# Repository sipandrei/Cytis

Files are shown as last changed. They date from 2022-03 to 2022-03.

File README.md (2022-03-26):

# Cytis

## Un aparat telecomandat pentru modificarea presiunii la biciclete

## Rezumat

De câte ori ai mers la o tură cu bicicleta și ai uitat să îți verifici presiunea din roți înainte de a pleca? Sau Poate ai decis să o iei pe macadam când aveai în plan doar asfalt lin și te-ai cam zdruncinat. Dacă ai pățit acestea, ei bine, Cytis îți poate veni în ajutor, dându-ți posibiliatea de a-ți regla presiunea direct de la telefon, sau orice dispozitiv cu bluetooth, acesta așteptând comenzile tale pe butucul roții. Din când în când va trebui schimbată canistra de aer.

## Din ce este Cytis compus?

Pentru început, acest proiect are două jumătăți: interfața web și dispozitivul în sine. Interfața web este construită în Ruby on Rails și configurată ca un Progressive Web App, pentru a putea fi instalată. Pe site este posibilă creearea unui cont(pentru autentificare am folosit Devise). Comunicarea este realizată folosind tehnologia Web Bluetooth. Dispozitivul este bazat pe un Arduino Nano cuplat cu un modul HM-10 pentru bluetooth. aerul de intrare este preluat dintr-o canistră de CO2, iar întreaga instalație este montată pe butucul roții pentru a încurca mai puțin.

**Proiectul se află în stadiul de prototip, o variantă de producție fiind mult mai mică și mai fiabilă, însă am fost limitat de buget**

## Cele patru lucruri principale pe care le face

- Procesează comenzile de la interfața web
- Citește presiunea actuală
- Umflă cauciucul
- Dezumflă cauciucul

## Tehnologii utilizate

- Arduino - partea fizică
- Ruby on Rails - backend-ul interfeței web
- HTML, CSS, JS - frontend-ul interfeței web
- Web Bluetooth - comunicarea cu dispozitivul fizic - limitează browserul ce poate fi utilizat
- PWA - permite instalarea site-ului

## Cerințe de Sistem

- Dispozitiv cu bluetooth, care poate accesa Internetul folosind Chrome(sau derivat) sau Opera

## Dorești să rulezi interfața web local?

- Ai nevoie de Ruby on Rails `v6.1.4` și Ruby `v3.0.3` instalat
- Rulează `git clone git@github.com:sipandrei/Cytis_frontend.git`
- Rulează `bundle install`
- Rulează `rails db:migrate`
- Pornește serverul și ar trebui să ai o interfață web Cytis ce rulează local

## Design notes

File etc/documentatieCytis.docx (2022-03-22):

Cytis

Aparat de ajustat presiunea cauciucurilor de la biciclete

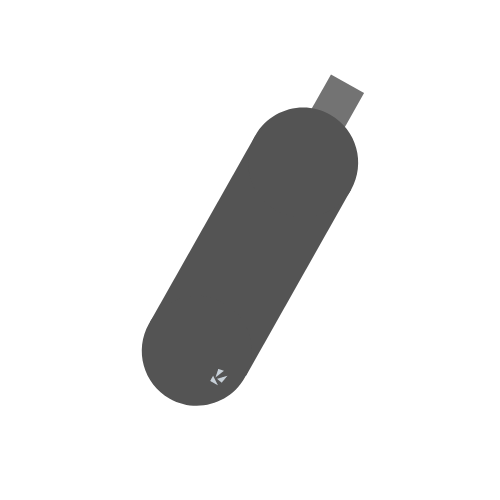
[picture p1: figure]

Elev: Pontoș Silviu Andrei

Profesor Coordonator: Burcuș Andrea

Martie 2022

Ce este Cytis?

Cytis este un proiect pe care l-am avut în minte o vreme bună, iar cu ocazia Olimpiadei de Inovare și Creație digitală – Infoeducație 2022, am fost motivat să îl pun în practică.

De unde a venit ideea. Care îi este scopul?

Fiind un adept al mersului cu bicicleta atât pe dealuri cât și pe șosele, în una dintre ieșirile mele combinate, am observat că fie aveam pe asfalt o presiune prea joasă, astfel fiind nevoit să depun mai mult efort pentru a mă deplasa cu o anumită viteză, fie aveam pe un drum noroios o presiune cu mult peste una cu care să mă simt în siguranță. O altă problemă apărea când nu eram obișnuit cu o anumită anvelopă sau pur și simplu uitam să verific presiunea înaintea turei, rezultatul evident fiind o pană în mijlocul sălbăticiei.

*POZA PANA IN SALBATICIE*

Așadar, pentru a evita situațiile neplăcute enumerate mai sus și după ce am auzit de un dispozitiv care măsoară presiunea în timpul deplasării, am decis că nu ar fi rău dacă aceasta ar putea fi și ajustată, lucru care nu l-am întâlnit încă la nici un produs.

Notă: În starea actuală proiectul reprezintă mai mult un Proof of Concept, o variantă de producție fiind mult mai compactă, dar, fiind limitat de bugetul pe care l-am avut, doar până aici am ajuns.

Bine, bine, dar numele de unde vine?

Denumirea de Cytis provine de la principala sursă de inspirație, și anume sistemele de umflare centralizată a cauciucurilor (central tire inflation system - CTIS), găsite cu precădere pe vehiculele militare cu roți pneumatice.

Cum funcționează?

Cytis este format din două elemente care lucrează împreună, și anume interfața web și partea fizică.

Interfața web

Interacțiunea cu dispozitivul se poate realiza folosind orice dispozitiv cu Bluetooth și care poate accesa Internetul prin intermediul Google Chrome sau Opera.

Interfața web a fost construită utilizând framework-ul Ruby on Rails pentru a permite utilizatorului să își salveze mai multe profile pentru presiune, astfel fiind mai rapidă setarea acesteia. Un profil conține două valori numerice, una pentru roata din spate, una pentru cea din față – în unitatea de măsură psi.

*POZĂ PRESET*

Controlarea propriu-zisă a presiunii se realizează pe o pagină dedicată a site-ului, iar conectarea se realizează cu ajutorul tehnologiei Web Bluetooth (de aici provenind limitarea la cele două browsere, fiind singurele care, la momentul scrierii, au implementată această tehnologie), care permite trimiterea și primirea de date de la dispozitive BLE (bluetooth low energy). Pe această pagină se poate conecta la Cytis, seta presiunea dorită și citi presiunea actuală.

*POZĂ INFLATOR*

Un adaos la interfața web este faptul că aceasta poate fi instalată, fiind configurată ca un PWA (progressive web app), dar la momentul actual service workerul nu salvează local paginile.

Partea Fizică

*POZĂ ASAMBLATE*

Centrul componentei hardware îl reprezintă un Arduino Nano, utilizat datorită dimensiunii reduse pe care o are și faptului că aveam acces la o astfel de placă. Comunicarea prin Bluetooth e realizată prin intermediul unui modul BLE HM-10, la care am adăugat pe pinul RX un reducător de la 5V la 3.3V format din două rezistoare(unul de 2kohm și celălalt de 4.7kohm).

*POZĂ CIRCUIT*

Atât pentru partea de „servire”, acum partea de muncă. Sursa principală de energie este o baterie de 9V. Ajustarea efectivă a presiunii este realizată utilizând două valve solenoid 2V025-06, una de ieșire una de intrare, conectate la Arduino folosind o punte h l298n. Citirea presiunii este realizată cu ajutorul unui transducer generic cu filet 1/4in. Presiunea pentru intrare vine dintr-o canistră de C02.

Toate elementele relevante pentru lucrul cu aerul sunt interconectate folosind tuburi pneumatice industriale de 6mm și două cupalje în T. Conectarea cu anvelopa se face prin intermediul valvei de pe jantă, prin intermediul unui adaptor care deschide valva de tip Schrader.

*POZĂ CAD LAYOUT*

Carcasa a fost proiectată folosind programul Onshape și ulterior printată 3D folosind PLA, aceasta fiind menită să fie prinsă pe butucul roții pentru a minimiza efectul greutății aparatului în caracteristicile de controlare a bicicletei.

Credite

Pentru codul necesar utilizării Web Bluetooth am avut ca bază următorul articol:

https://loginov-rocks.medium.com/how-to-make-a-web-app-for-your-own-bluetooth-low-energy-device-arduino-2af8d16fdbe8

Mulțumesc magazinului de biciclete CsaBike pentru componentele specifice pentru bicicletă, magazinului Domus Energy pentru cablurile pe care le-am primit și prietenilor care m-au ajutat cu imprimarea carcasei.

Surse

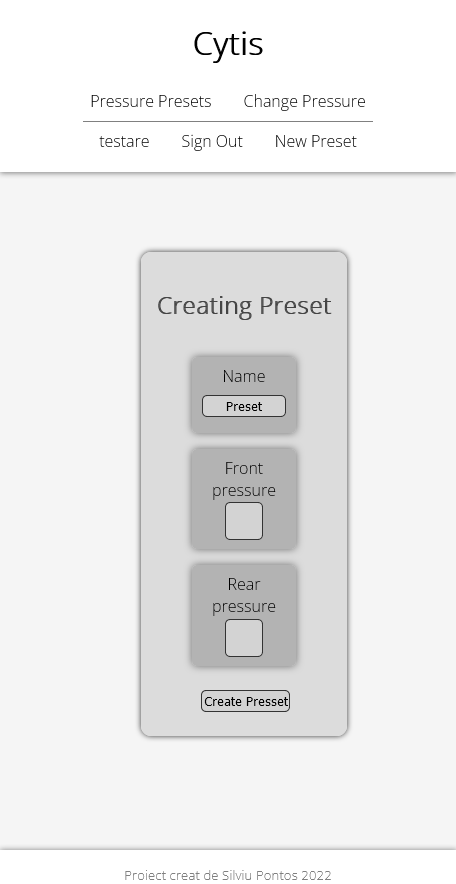
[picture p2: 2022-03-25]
etc/Captura de ecran 2022-03-25 la 08.28.39.png

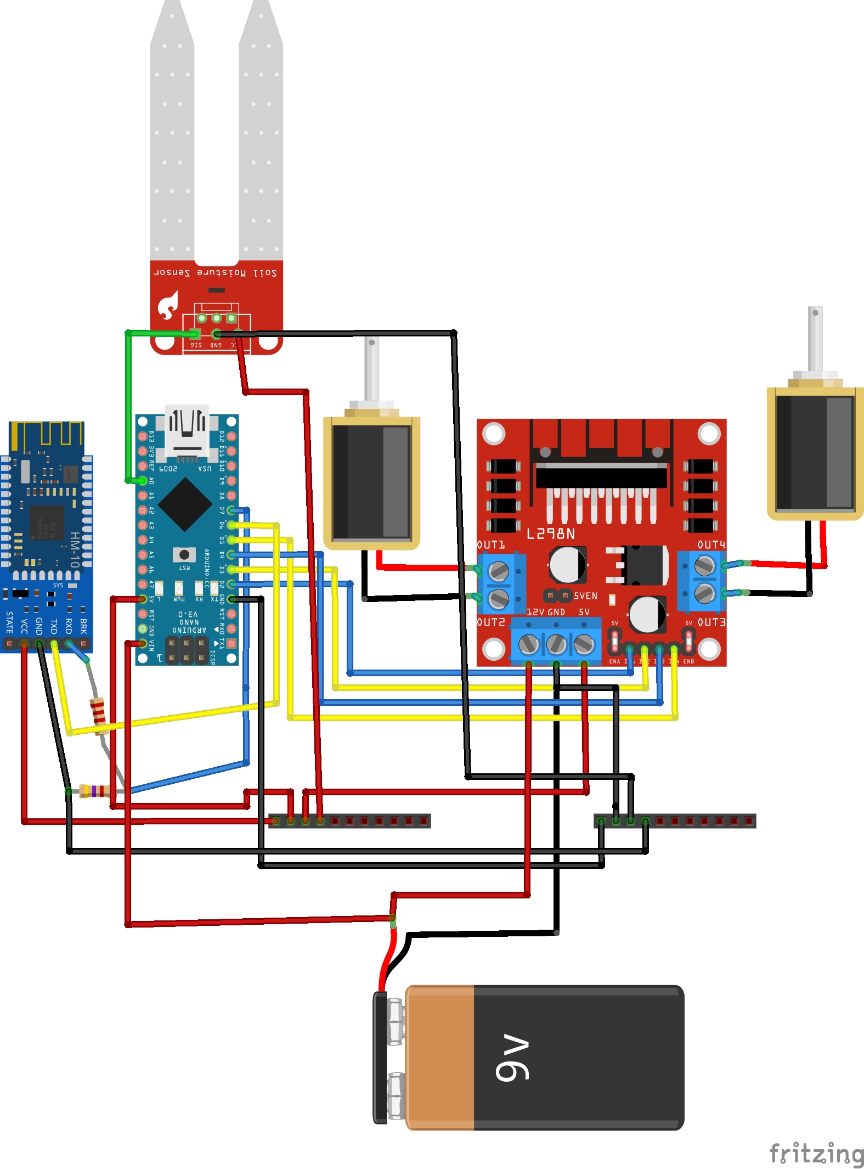
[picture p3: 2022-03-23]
etc/Cytis_bb.jpg

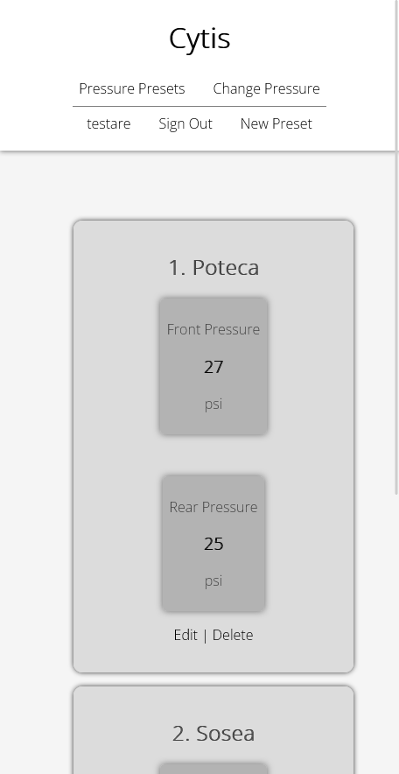
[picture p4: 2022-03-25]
etc/Captura de ecran 2022-03-25 la 07.57.08.png

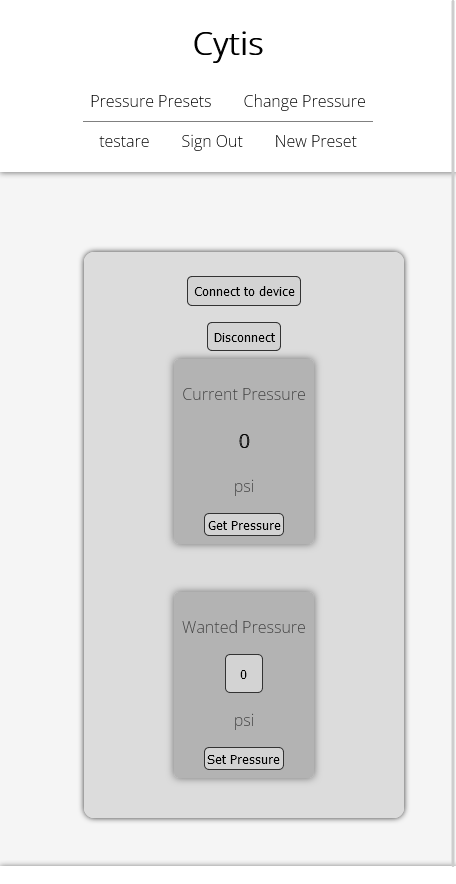
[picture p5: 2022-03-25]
etc/Captura de ecran 2022-03-25 la 07.58.17.png

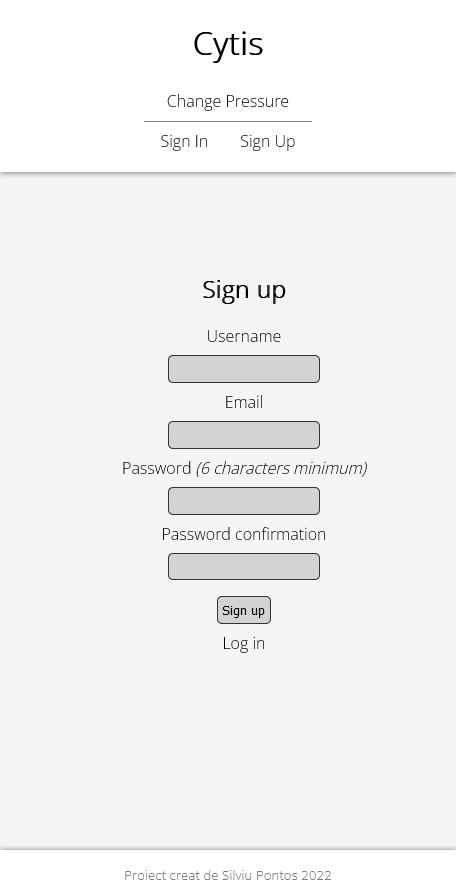
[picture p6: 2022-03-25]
etc/Captura de ecran 2022-03-25 la 08.36.11.png

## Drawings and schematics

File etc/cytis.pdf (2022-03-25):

Documentație

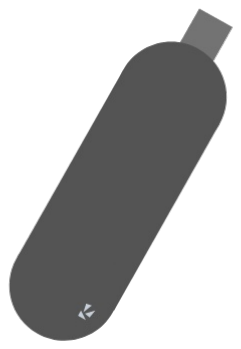
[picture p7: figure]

Elev: Pontoș Silviu Andrei

Profesori Coordonatori:
Burcuș Andrea, Hotea
Cornelia

# Cytis

Aparat de ajustat presiunea cauciucurilor de la biciclete

## Ce este Cytis?

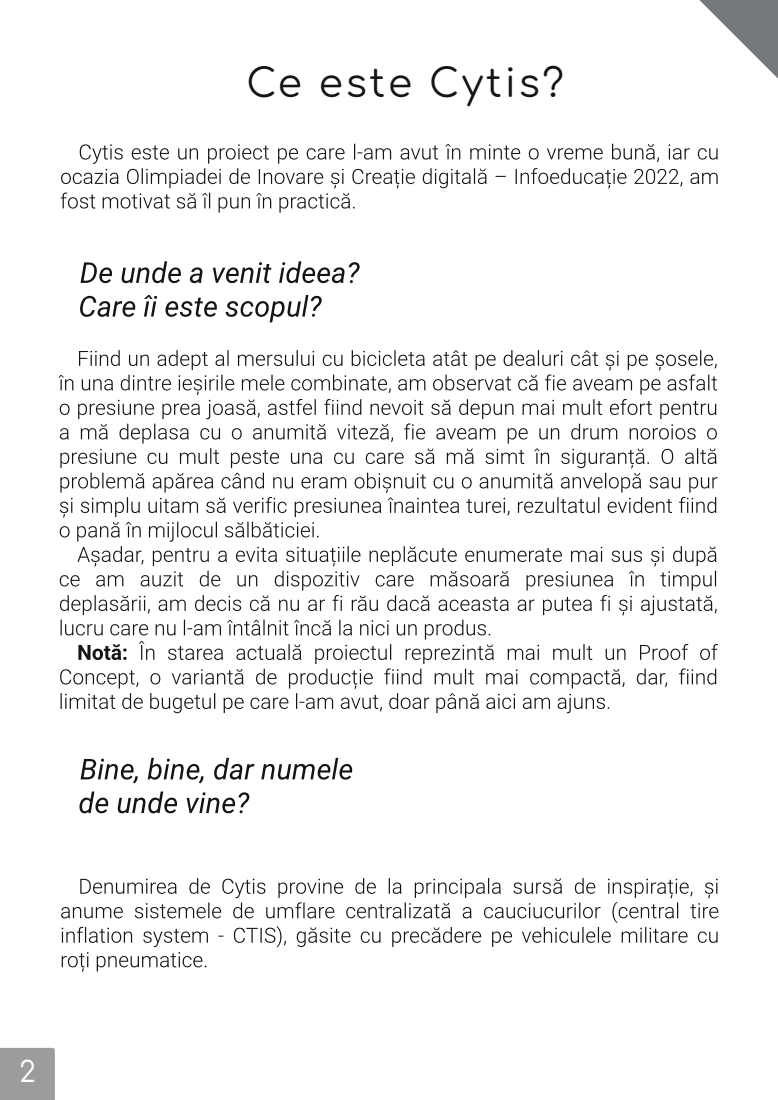
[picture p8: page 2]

## Cum funcționează?

## Interfața web

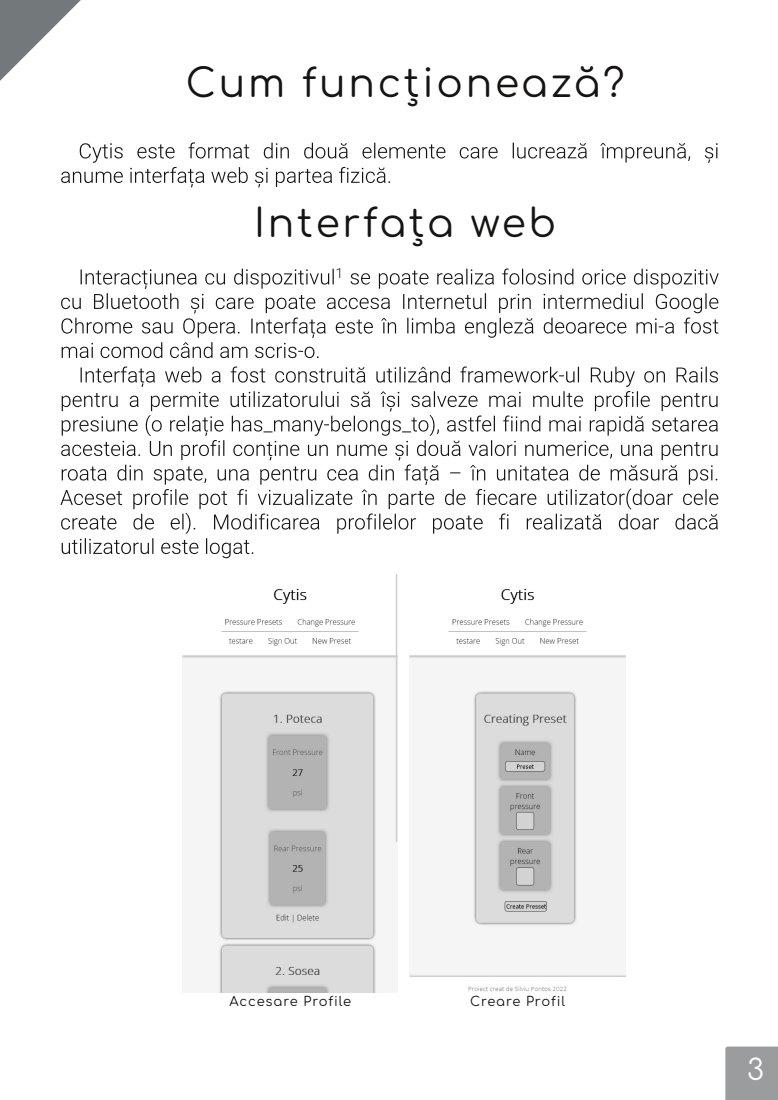
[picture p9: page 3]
Accesare Profile; Creare Profil

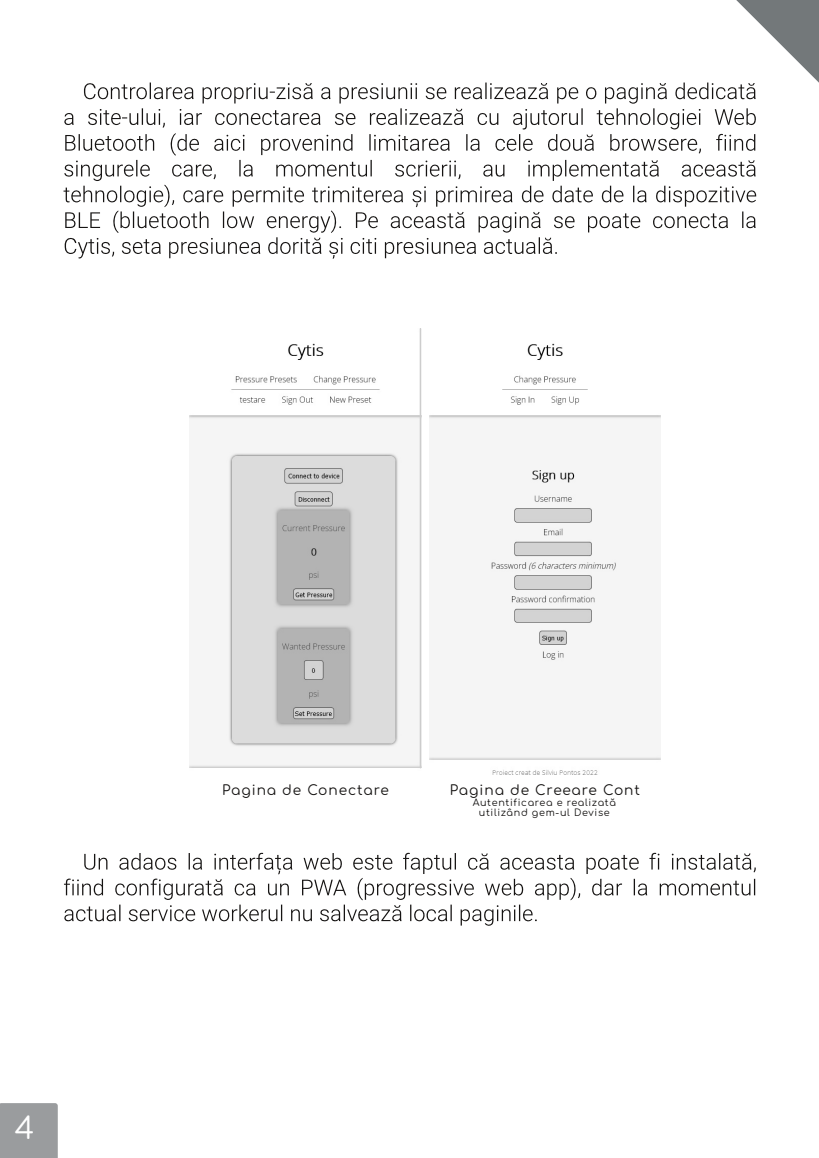
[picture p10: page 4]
Pagina de Conectare; Pagina de Creeare Cont

Autentificarea e realizată
utilizând gem-ul Devise

## Partea Fizică

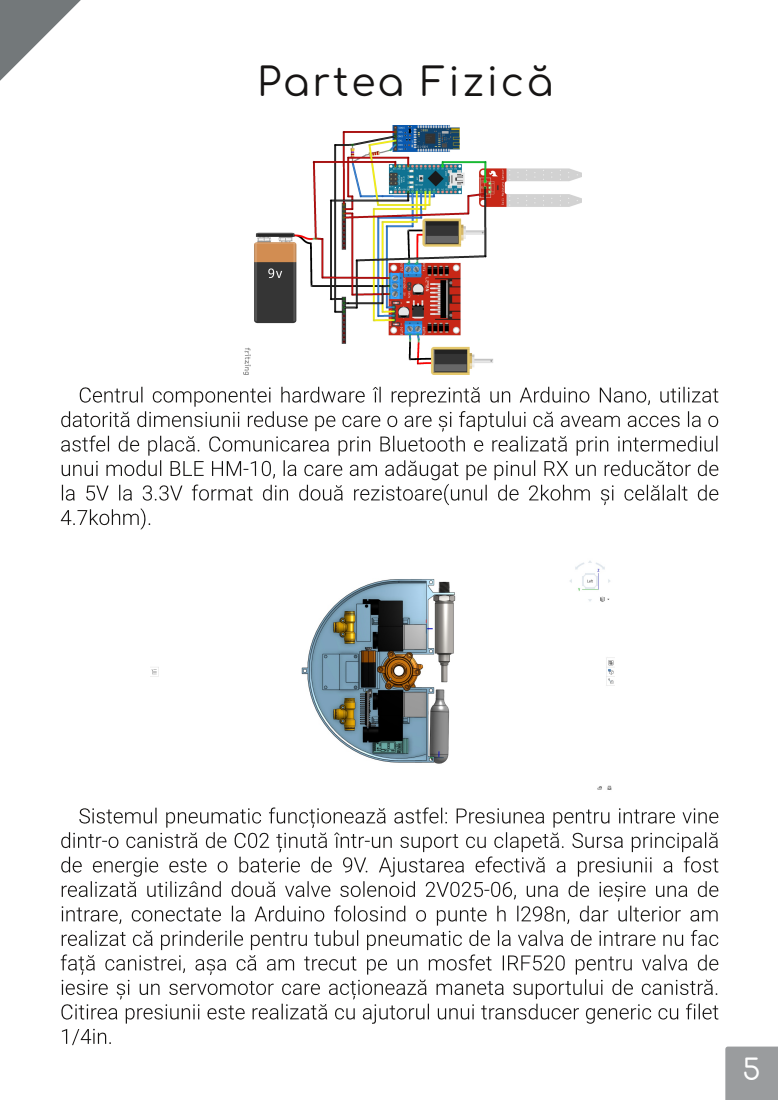
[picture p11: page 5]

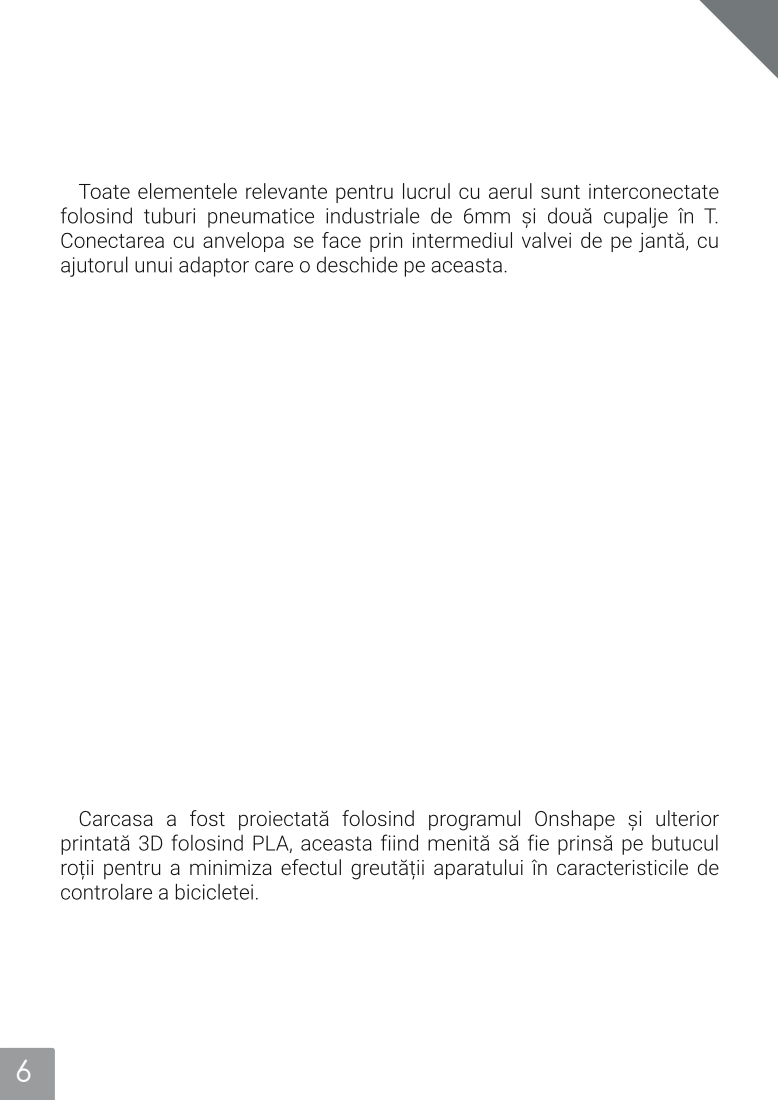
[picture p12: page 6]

## Mențiuni

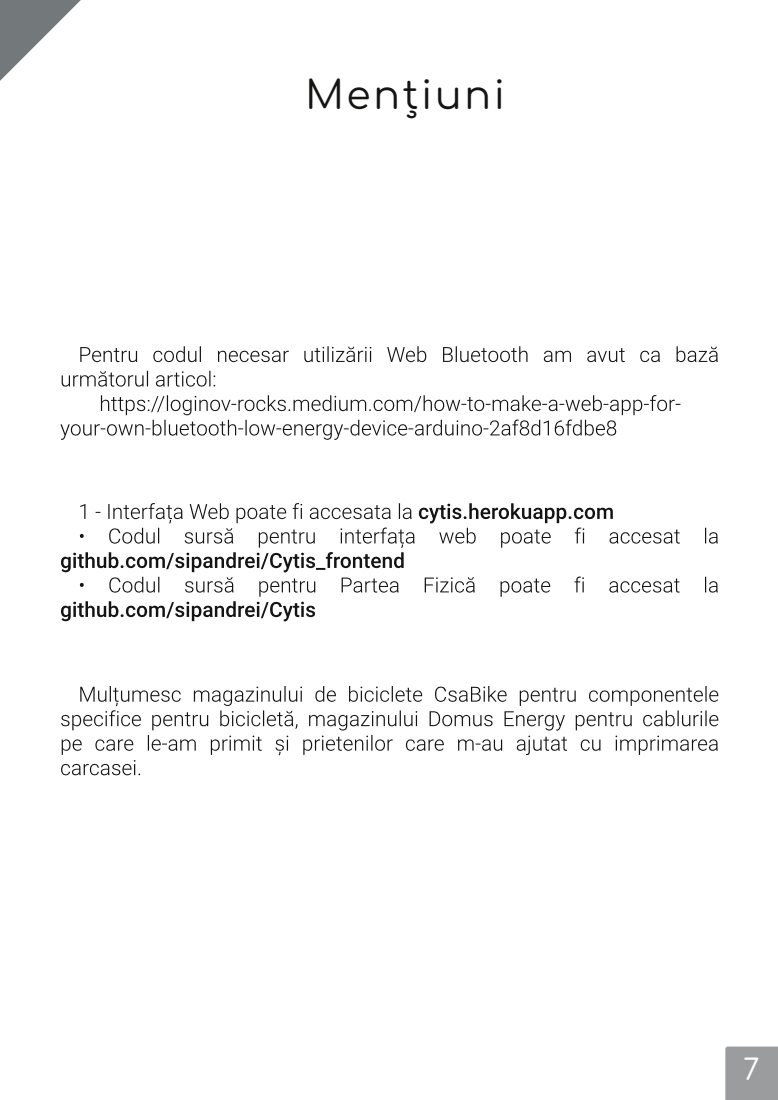
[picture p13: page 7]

## Listă componente și tehnologii utilizate

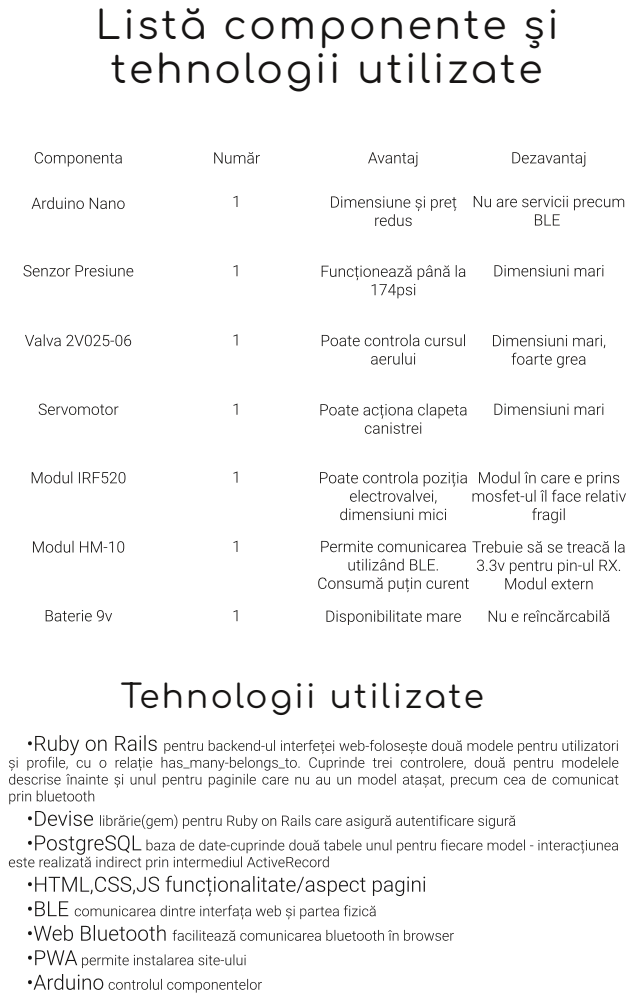
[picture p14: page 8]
Tehnologii utilizate

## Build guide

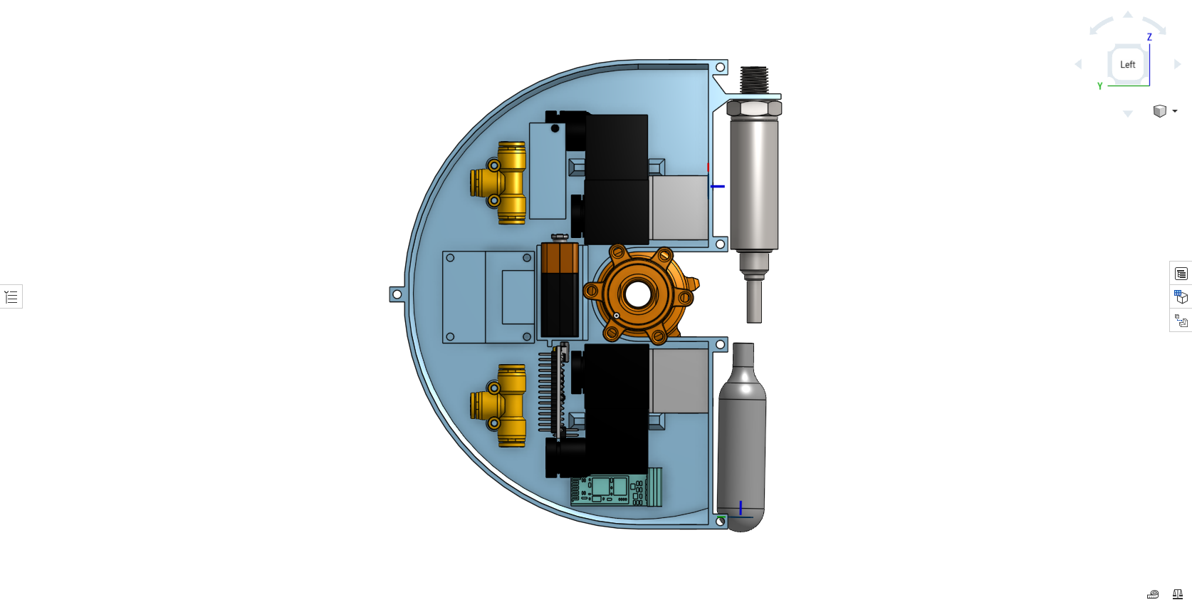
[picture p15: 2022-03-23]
etc/Screenshot 2022-03-23 at 22-19-41 Cytis Assembly 1.png

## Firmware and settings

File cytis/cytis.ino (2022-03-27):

#include <SoftwareSerial.h>
#include <Servo.h>
#include <string.h>

Servo servoIntake;
const int pressurePin = A0;
const float voutLower = 0.5;
const float voutUpper = 4.5;
const int transducerMaxPsi = 174;
const int exhaustPin = 2;
const int servoPin = 5;
const int tx = 4, rx = 3;
float pressureValue = 0;
float currentPressurePsi = 0;
float pressureVolts = 0;
int targetPressure;
char serialInput[16];
bool toSetPressure = false;

SoftwareSerial ble(rx, tx);

// functie pentru a transforma valoarea de pe pinul analogic in psi
float analogToPsi(float analogValue){
  pressureVolts = analogValue * 5.0 / 1023.0;
  return transducerMaxPsi * ((pressureVolts - voutLower) / (voutUpper - voutLower));
}

void pressureDebugDisplay(){
  Serial.print(toSetPressure);
  Serial.print(" Value ");
  Serial.print(pressureValue);
  Serial.print(" Volt ");
  Serial.print(pressureVolts);
  Serial.print(" Pressure ");
  Serial.print(currentPressurePsi);
  Serial.println("psi");
}

void openValve(int valvePin) {
  digitalWrite(valvePin, HIGH);
}

void closeValve(int valvePin) {
  digitalWrite(valvePin, LOW);
}

// ciclaza valva la 100 milisecunde
void valveCycle(int valvePin) {
  openValve(valvePin);
  delay(100); //valve open time
  closeValve(valvePin);
}

// initializeaza valva si servoul
void pinsLow() {
  digitalWrite(exhaustPin, LOW);
  servoIntake.write(0);
  delay(10);
 }

int wholePart(float number) {
  int wholeNum;
  wholeNum = number;
  return wholeNum;
}

// controlul servoului, se misca 110 de grade
void pressureIn(Servo servo){
  
  for(int pos = 0; pos <= 110; pos++){
    servo.write(pos);
    delay(10);
  }
}

// functia pentru ajustarea presiunii, lasa daca e prea mare, introduce daca e prea mica
void pressureAdjust(int intakePin, int exhaustPin) {
  readPressure();
  if(wholePart(currentPressurePsi) >= targetPressure)
     valveCycle(exhaustPin);//let pressure out
  else
    {
      pressureIn(servoIntake); // let pressure in
      servoIntake.write(0);
      delay(20);
      toSetPressure = false; // failsafe for servo
    }

  if(wholePart(currentPressurePsi) == targetPressure)
    {
      toSetPressure = false;
      Serial.println("Pressure Adjusted");
    }
}

// initializeaza presiunea tinta cu valoarea actuala, just for peace of mind
void initializeTargetPressure() {
  pressureValue = analogRead(pressurePin);
  currentPressurePsi = analogToPsi(pressureValue);
  targetPressure = currentPressurePsi;
}

// procesarea comenzilor de la bluetooth
void commandProcessing(char command[]) {   
  Serial.println(command);
  Serial.println(strcmp(command, "c")); // comanda c returneaza presiunea curenta
  if(strcmp(command, "c") == 0){
    Serial.print('.');
    ble.print("current ");
    ble.println(currentPressurePsi);
  }
  else if (strstr(command, "setPressure")) { // comanda setPressure <numar> schimba presiunea tinta si incepe a merge spre ea
    char* slicedCommand = strtok(command, " ");   
    slicedCommand = strtok(NULL, " ");
    if(atoi(slicedCommand) != 0)
    {
      targetPressure = atoi(slicedCommand);
      Serial.print("target pressure set to ");
      Serial.println(targetPressure);
      toSetPressure = true;
      Serial.println("Pressure is adjusting to given target...");
    }
    else
      Serial.println("givenPressure is NULL");
  }
}

void readPressure(){
  pressureValue = analogRead(pressurePin);
  currentPressurePsi = analogToPsi(pressureValue);
}

void setup(){
  Serial.begin(9600);
  servoIntake.attach(servoPin);
  ble.begin(9600);
  ble.println("Connected to Cytis");
  Serial.print("Welcome to Cytis\n");
  pinMode(tx, OUTPUT);
  pinMode(rx, INPUT);
  pinMode(exhaustPin, OUTPUT);
  pinsLow();
  initializeTargetPressure();
}

void loop(){
  int letter = 0;
  readPressure();
  if(ble.available() > 0){ // citirea comenzilor de la bluetooth
    while(ble.available() > 0){
      serialInput[letter] = ble.read();
      letter++;
    }
    serialInput[letter]='\0';
    commandProcessing(serialInput);
  }
  if (toSetPressure) { // actioneaza schimbarea presiunii doar imediat dupa o comanda setPressure
    pressureAdjust(servoPin, exhaustPin);
    delay(20);
    servoIntake.write(0);
  }
  pressureDebugDisplay();
  
  delay(500);
}

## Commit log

2022-03-06 fritzing schematic
    [Cytis.fzz]
2022-03-07 added transformation from analog input to psi for pressure transducer
2022-03-09 added functions for pressure regulation
2022-03-09 added pins and tested on board
2022-03-12 fixed bluetooth commands and when to stop adjusting the pressure
    [cytis.ino]
2022-03-13 interaction with web interface for getting pressure
2022-03-21 reading pressure one more time in valveCycle function
2022-03-26 working with servo and finished documentation
2022-03-27 unghi mai mare la servo
